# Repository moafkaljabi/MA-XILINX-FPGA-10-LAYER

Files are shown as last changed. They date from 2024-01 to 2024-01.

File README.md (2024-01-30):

# MA-XILINX

                                Front
MA_Inventtronics-FRONT-3D

                                Back
MA_Inventtronics-BACK-3D

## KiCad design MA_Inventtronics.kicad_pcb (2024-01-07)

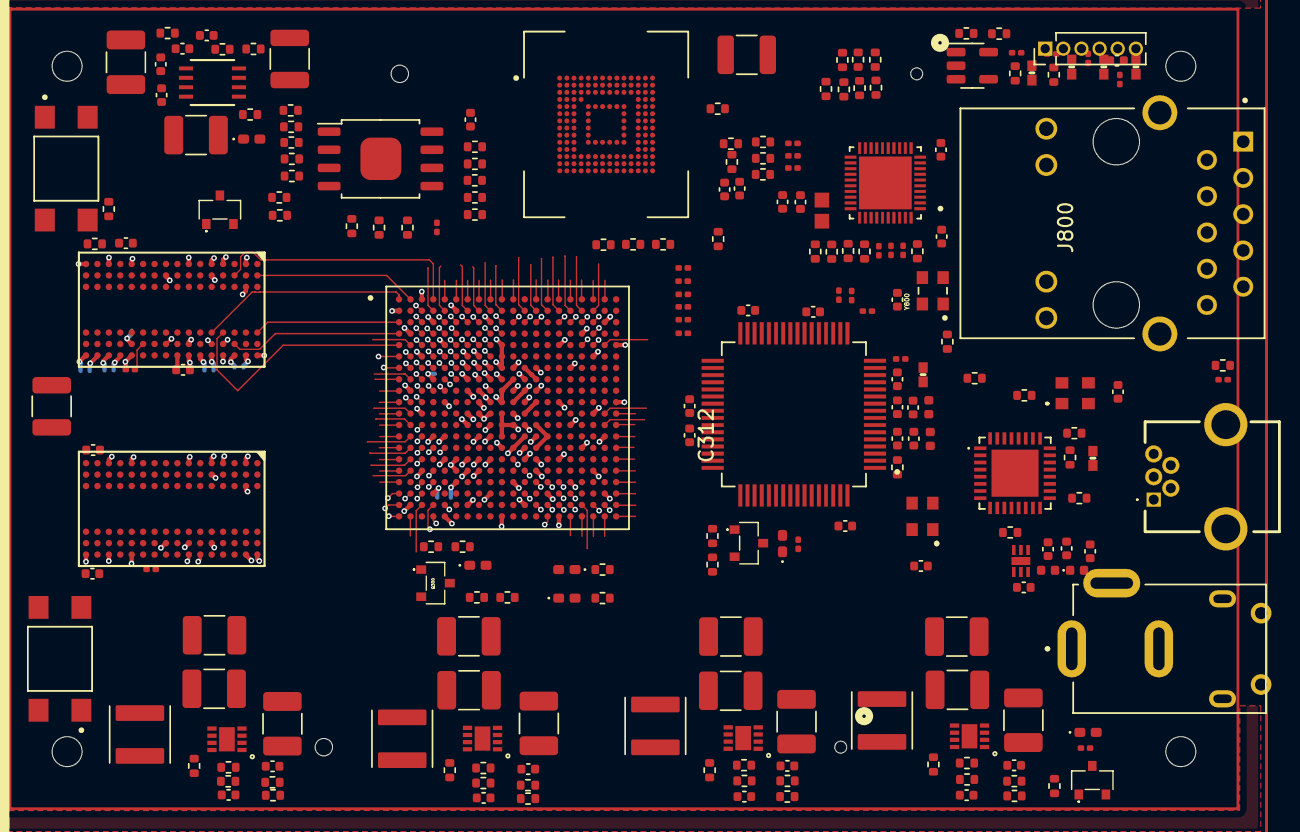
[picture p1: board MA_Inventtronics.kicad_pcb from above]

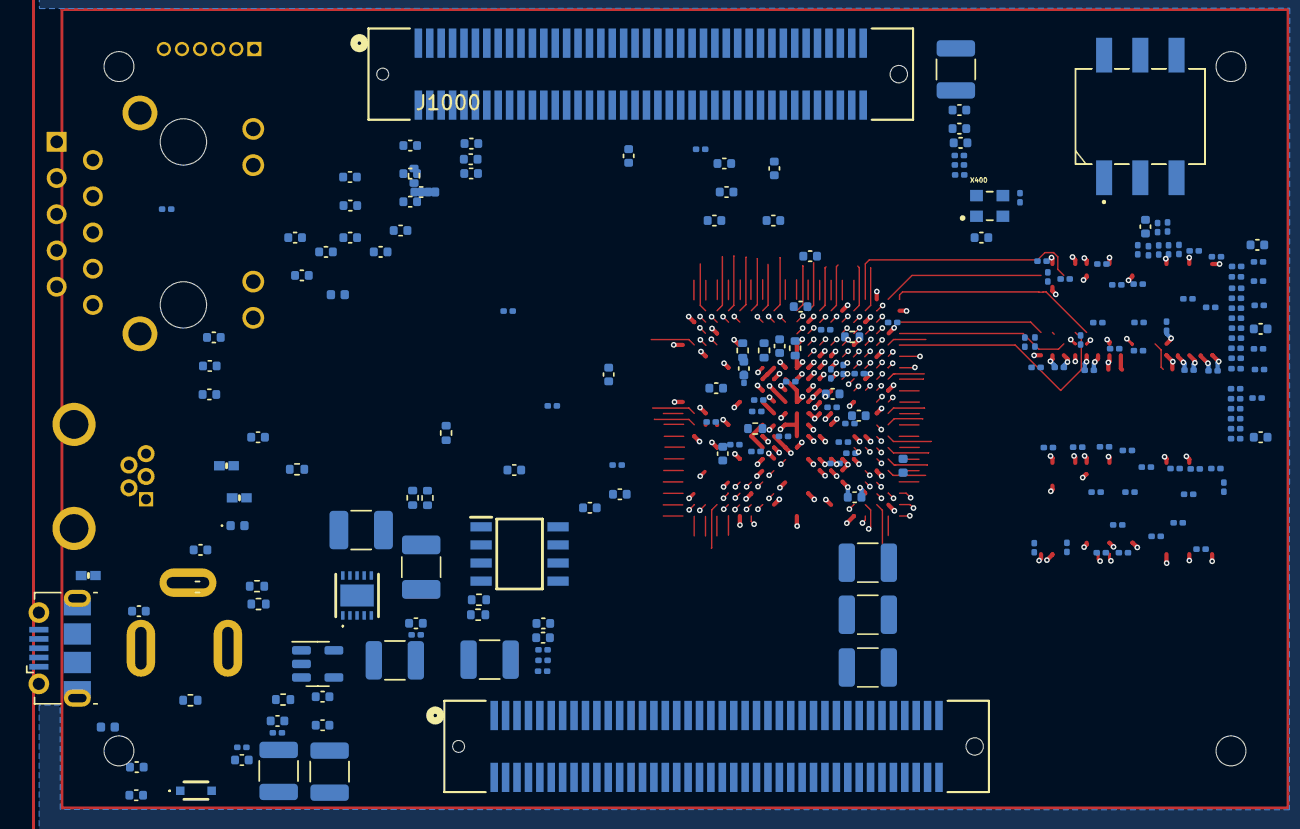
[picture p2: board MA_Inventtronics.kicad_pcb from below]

Board: 10 copper layers, 429 parts (207 on the bottom side), 351 nets.

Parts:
C100, C103, C104, C107, C108, C109, C112, C113, C114, C117, C118, C119, C122, C123, C124, C127: 22u; C_1210_3225Metric_Pad1.33x2.70mm_HandSolder
C101, C102, C105, C110, C115, C120, C300, C304, C306, C307, C308, C309, C310, C311, C312, C313, C314, C316, C318, C400, C401, C402, C403, C404, C405, C406, C407, C409, C412, C801, C802, C803, C804, C805, C806, C807, C808, C810, C811, C813, C815, C817, C818, C900, C901, C902, C903, C904, C905, C906, C908: 100n; C_0402_1005Metric
C106, C111, C116, C121: 22p; C_0402_1005Metric
C125, C126, C128, C129, C201, C205, C210, C213, C216, C220, C223, C229, C232, C237, C239, C244, C246, C301, C302, C303, C305, C315, C408, C410, C411, C413, C608, C609, C610, C611, C702, C712, C724, C734, C800, C809, C812, C814, C816, C819, C907: 4u7; C_0402_1005Metric
C130: 1n; C_0201_0603Metric
C200, C204, C209, C212, C221, C224, C230, C233, C234, C235, C248: 100u; C_1210_3225Metric
C202, C203, C206, C207, C208, C211, C214, C215, C217, C218, C219, C222, C225, C226, C228, C231, C238, C240, C241, C242, C243, C245, C247, C604, C605, C606, C607, C703, C713, C725, C735: 470n; C_0201_0603Metric
C227, C236: 470n; C_0402_1005Metric
C600, C601, C602, C603, C612, C613, C700, C701, C704, C705, C706, C707, C708, C709, C710, C711, C714, C715, C716, C717, C718, C719, C720, C721, C722, C723, C726, C727, C728, C729, C730, C731, C732, C733, C736, C737, C738, C739, C740, C741, C742, C743: 47n; C_0201_0603Metric
D100: PMEG1030EJ; PMEG1030EJ115
D101: LED; LED_0402_1005Metric_Pad0.77x0.64mm_HandSolder
D300, D308, D309: LED_G; LED_0402_1005Metric_Pad0.77x0.64mm_HandSolder
D301, D302, D303, D304, D306, D307, D900, D901, D902: CG0402MLU-3.3G; VARC1005X41N
D305, D903: PMEG1030EJ; D_0402_1005Metric
D400: D400; LED_0402_1005Metric_Pad0.77x0.64mm_HandSolder
D500: GREEN; LED_0402_1005Metric_Pad0.77x0.64mm_HandSolder
FB200, FB300, FB301, FB302, FB800, FB801, FB900: 120R; L_0402_1005Metric
H901, H902, H903, H904: MountingHole; MountingHole_2.1mm
J100: Barrel_Jack_Switch; GRAVITECH_CON-SOCJ-2155
J302: USB_B_Micro; USB_Micro-B_Molex-105017-0001
J304: PinHeader_1x06_P1.27mm_Vertical
J800: HR911130A; HANRUN_HR911130A
J900: GMSB0522132EU
J1000, J1001: 10144518-082802LF; CONN_10144518_AMP
L100, L101, L102, L103: 2u2; L_Abracon_ASPI-4030S
L800: LQM18PN3R3MGHD; INDC1608X100N
Q100, Q300, Q400, Q500: T2N7002AK,LM; TBAT54CLM
R100, R104, R109, R114, R119, R126, R401: 100k; R_0402_1005Metric
R101, R103, R105, R108, R110, R113, R115, R118, R120, R123, R125: 12k; R_0402_1005Metric
R102, R300, R301, R302, R303, R304: 4k7; R_0402_1005Metric
R106, R421, R422, R423, R424, R425: 68K; R_0402_1005Metric
R107, R112, R117, R122, R322, R323, R414, R416, R501: 100K; R_0402_1005Metric
R111: 200K; R_0402_1005Metric
R116: 124K; R_0402_1005Metric
R121: 453K; R_0402_1005Metric
R124, R503, R823: 510R; R_0201_0603Metric
R127, R311, R313, R315, R500, R803, R805, R806, R813, R814: 1K; R_0402_1005Metric
R128: DNP_1M; R_0402_1005Metric
R305, R306, R307, R308, R329, R330, R331, R332, R333, R334, R335, R406, R407, R408, R409, R410, R411, R419, R420, R427, R807, R811, R812, R815, R816, R817: 22R; R_0201_0603Metric
R309, R336, R337, R412, R822: 510R; R_0402_1005Metric
R310, R312, R314, R316, R318, R319, R321, R338, R404, R405: 20K; R_0402_1005Metric
R317, R320, R428: DNP_0R; R_0402_1005Metric
R324, R326, R327, R328, R400, R402, R403, R413, R417, R418, R426, R502, R903: 12K; R_0402_1005Metric
R325, R821: 2K49; R_0402_1005Metric
R600, R626, R627: 100R; R_0201_0603Metric
R601, R602, R603, R604, R605, R606, R607, R608, R609, R610, R611, R612, R613, R614, R615, R616, R617, R618, R619, R620, R621, R622, R623, R624: 49R9; R_0201_0603Metric
R625, R800, R801, R804, R818, R819, R820, R904, R905: 4K7; R_0402_1005Metric
R700, R701: 240R; R_0201_0603Metric
R802: DNP_4K7; R_0402_1005Metric
R808, R809, R810, R901: 22R; R_0402_1005Metric
R900: 1k; R_0402_1005Metric
R902: 8K06; R_0402_1005Metric
SW300, SW400: TL3305BF160QG; SW_TL3305BF160QG
SW301: 219-3LPST; 2193LPST
U100: LS1205EVD33
U101, U102, U103, U104: SY8003ADFC; SON50P200X200X65-9N
U105: BD3539FVM-TR; MSOP8_ROM
U200: XC7Z007S-1CLG400C; BGA400C80P20X20_1700X1700X160N
U300: FT2232HL-REEL; QFP50P1200X1200X160-64N
U301: 93LC56B-I_SN; SOIC127P600X175-8N
U400, U401: SN74LVC1G14DBV; SOT-23-5
U403: S40FC004C1B1I00000; BGA153N50P14X14_1150X1300X80
U404: W25Q128JVEIQ; SOIC-8_5.23x5.23mm_P1.27mm
U700, U701: MT41K256M16TW-107_P; TFBGA-96
U800: RTL8211F-CG; QFN40P500X500X90-41N
U900: USB3320C-EZK-TR; QFN50P500X500X100-33N330X330
U901: MIC2099-1YMT-TR; TMLF-6_MT_MCH
X300: ECS-2520MV-120-BN-TR; ECS2520MV120BNTR
X400: ECS-2520MV-333.3-BN-TR; OSC_ECS-2520S25-250-FN-TR
Y800: ECS-2520MV-250-BN-TR; OSC_ECS-2520S25-250-FN-TR
Y900: ECS-2520MV-130-BN-TR; ECS2520MV130BNTR

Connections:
+5V: C104.1, C109.1, C114.1, C119.1, R103.1, R105.1, R108.1, R113.1, R118.1, U101.3 (IN), U102.3 (IN), U103.3 (IN), U104.3 (IN)
/1. Power/DDR_VTT_EN: C125.1, R125.2, R126.1, R127.2, U105.2 (EN), U105.5 (VDDQ)
/1. Power/EN_1V0: R105.2, R110.2, R115.2, R120.2, U101.7 (EN), U102.7 (EN), U103.7 (EN), U104.7 (EN)
/1. Power/FB 1V0: C106.2, C111.2, C116.2, C121.2, R106.2, R107.1, R111.2, R112.1, R116.2, R117.1, R121.2, R122.1, U101.1 (FB), U102.1 (FB), U103.1 (FB), U104.1 (FB)
/1. Power/LED_PWR_A: D101.2 (A), R124.2
/1. Power/LED_PWR_C: D101.1 (K), Q100.2 (S)
/1. Power/PG_1V0: C105.1, C110.1, C115.1, C120.1, R103.2, R104.1, R108.2, R109.1, R113.2, R114.1, R118.2, R119.1, R123.2, U101.2 (PG), U102.2 (PG), U103.2 (PG), U104.2 (PG)
/1. Power/PWR_EN: C101.1, R100.2, U100.7 (EN)
/1. Power/SW_1V0: L100.1, L101.1, L102.1, L103.1, U101.6 (LX), U102.6 (LX), U103.6 (LX), U104.6 (LX)
/1. Power/eFuse_ILIM: R102.1, U100.5 (ILIM)
/1. Power/eFuse_SS: C102.1, U100.6 (SS)
/1. Power/eFuse_VCP: R101.1, U100.4 (VCP)
/3. Zynq Config, JTAG, Debug/CLK 12 MHZ: R338.1, X300.3 (OUT)
/3. Zynq Config, JTAG, Debug/DONE: Q300.1 (G), R302.2, U200.R11 (DONE_0)
/3. Zynq Config, JTAG, Debug/FTDI EECLK: R326.1, U300.62 (EECLK), U301.2 (CLK)
/3. Zynq Config, JTAG, Debug/FTDI EECS: R327.1, U300.63 (EECS), U301.1 (CS)
/3. Zynq Config, JTAG, Debug/FTDI EEDAT: R325.2, U300.61 (EEDATA), U301.3 (DI)
/3. Zynq Config, JTAG, Debug/FTDI NRST: R322.1, R323.2, U300.14 (~RESET)
/3. Zynq Config, JTAG, Debug/FTDI OSCI: R338.2, U300.2 (OSCI)
/3. Zynq Config, JTAG, Debug/FTDI REF: R328.2, U300.6 (REF)
/3. Zynq Config, JTAG, Debug/FTDI RX: R335.2, U300.39 (BDBUS1)
/3. Zynq Config, JTAG, Debug/FTDI TCK: R329.1, U300.16 (ADBUS0)
/3. Zynq Config, JTAG, Debug/FTDI TDI: R330.1, U300.17 (ADBUS1)
/3. Zynq Config, JTAG, Debug/FTDI TDO: R331.1, U300.18 (ADBUS2)
/3. Zynq Config, JTAG, Debug/FTDI TMS: R332.1, U300.19 (ADBUS3)
/3. Zynq Config, JTAG, Debug/FTDI TX: R334.2, U300.38 (BDBUS0)
/3. Zynq Config, JTAG, Debug/FTDI VPHY: C305.1, C306.1, FB302.2, U300.4 (VPHY)
/3. Zynq Config, JTAG, Debug/FTDI VPLL: C303.1, C304.1, FB301.2, U300.9 (VPLL)
/3. Zynq Config, JTAG, Debug/FTDI_RX_LED_A: D308.2 (A), R336.2
/3. Zynq Config, JTAG, Debug/FTDI_RX_LED_K: D308.1 (K), U300.54 (BCBUS3)
/3. Zynq Config, JTAG, Debug/FTDI_TX_LED_A: D309.2 (A), R337.2
/3. Zynq Config, JTAG, Debug/FTDI_TX_LED_K: D309.1 (K), U300.55 (BCBUS4)
/3. Zynq Config, JTAG, Debug/LED_DONE_A: D300.2 (A), R309.2
/3. Zynq Config, JTAG, Debug/LED_DONE_C: D300.1 (K), Q300.3 (D)
/3. Zynq Config, JTAG, Debug/M0: R310.1, R315.1, SW301.1
/3. Zynq Config, JTAG, Debug/M1: R312.1, R313.1, SW301.2
/3. Zynq Config, JTAG, Debug/M2: R311.1, R314.2, SW301.3
/3. Zynq Config, JTAG, Debug/M3: R316.2, R317.2, R318.1
/3. Zynq Config, JTAG, Debug/M4: R319.2, R320.2, R321.1
/3. Zynq Config, JTAG, Debug/NINIT: R303.2, U200.R10 (INIT_B_0)
/3. Zynq Config, JTAG, Debug/NPROGARAM: R304.2, SW300.3, SW300.4, U200.L6 (PROGRAM_B_0)
/3. Zynq Config, JTAG, Debug/USB FTDI D N: D306.2, D307.2, J302.2 (D-), U300.7 (DM)
/3. Zynq Config, JTAG, Debug/USB FTDI D P: J302.3 (D+), U300.8 (DP)
/3. Zynq Config, JTAG, Debug/VUSB FILTER: C302.1, D305.2 (A), FB300.2, R322.2
/4. Zynq Processing System (PS)/CLK 33M33: R420.1, X400.3 (OUT)
/4. Zynq Processing System (PS)/FLASH CLK M4: R419.2, U404.6 (CLK)
/5. Zynq Programmable Logic (PL)/LED PL: R501.1, R502.1, U200.T12 (IO_L2P_T0_34)
/5. Zynq Programmable Logic (PL)/NPUDC: R500.2, U200.U13 (IO_L3P_T0_DQS_PUDC_B_34)
/6. Zynq DDR Interface & Termination/DDR NRST: R625.2, U200.B4 (PS_DDR_DRST_B_502)
/7. 1GB DDR3L Modules/DDR ZQ1: R700.1, U700.L8 (ZQ)
/7. 1GB DDR3L Modules/DDR ZQ2: R701.1, U701.L8 (ZQ)
/8. Gigabit Ethernet/CLK 25MHZ: R815.1, Y800.3 (OUT)
/8. Gigabit Ethernet/ETH CLK 25MHZ: R815.2, U800.37 (XTAL_OUT/EXT_CLK)
/8. Gigabit Ethernet/ETH PHY RXCLK: R812.2, U800.27 (RXC/PHYAD1)
/8. Gigabit Ethernet/ETH PHY RXCTL: R811.2, U800.26 (RXCTL/PHYAD2)
/8. Gigabit Ethernet/ETH PHY RXD0: J800.2, J800.4, J800.5, J800.8, R807.2, U800.1 (MDIP0), U800.4 (MDIP1), U800.6 (MDIP2), U800.9 (MDIP3), U800.25 (RXD0/RXDLY)
/8. Gigabit Ethernet/ETH PHY RXD1: J800.3, J800.6, J800.7, J800.9, R808.2, U800.2 (MDIN0), U800.5 (MDIN1), U800.7 (MDIN2), U800.10 (MDIN3), U800.24 (RXD1/TXDLY)
/8. Gigabit Ethernet/ETH PHY RXD2: R809.2, U800.23 (RXD2/PLLOFF)
/8. Gigabit Ethernet/ETH PHY RXD3: R810.2, U800.22 (RXD3/PHYAD0)
/8. Gigabit Ethernet/ETH REG OUT: L800.1, U800.30 (REG_OUT)
/8. Gigabit Ethernet/ETH RSET: R821.2, U800.39 (RSET)
/8. Gigabit Ethernet/ETH XTAL IN: R816.1, U800.36 (XTAL_IN)
/8. Gigabit Ethernet/ETH XTALOUT: R817.1, U800.35 (CLKOUT)
/9. USB 2.0 High-Speed (OTG)/CLK 13MHZ: R901.1, Y900.3 (OUT)
/9. USB 2.0 High-Speed (OTG)/USB HS D N: D900.2, J900.2 (D-), U900.19 (DM)
/9. USB 2.0 High-Speed (OTG)/USB HS D P: D901.2, J900.3 (D+), U900.18 (DP)
/9. USB 2.0 High-Speed (OTG)/USB HS ID: D902.2, J900.4 (ID), U900.23 (ID)
/9. USB 2.0 High-Speed (OTG)/USB HS VBUS FILT: C905.1, D903.1 (K), FB900.1, R903.2
/9. USB 2.0 High-Speed (OTG)/USB ILM: R905.1, U901.2 (ILIMIT)
/9. USB 2.0 High-Speed (OTG)/USB PHY RBIAS: R902.1, U900.24 (RBIAS)
/9. USB 2.0 High-Speed (OTG)/USB PHY VBUS: R903.1, U900.22 (VBUS)
/9. USB 2.0 High-Speed (OTG)/USB REFCLK 13MHZ: R901.2, U900.26 (REFCLK)
DDR A0: R609.1, U200.N2 (PS_DDR_A0_502), U700.N3 (A0), U701.N3 (A0)
DDR A1: R610.1, U200.K2 (PS_DDR_A1_502), U700.P7 (A1), U701.P7 (A1)
DDR A2: R611.1, U200.M3 (PS_DDR_A2_502), U700.P3 (A2), U701.P3 (A2)
DDR A3: R612.1, U200.K3 (PS_DDR_A3_502), U700.N2 (A3), U701.N2 (A3)
DDR A4: R613.1, U200.M4 (PS_DDR_A4_502), U700.P8 (A4), U701.P8 (A4)
DDR A5: R614.1, U200.L1 (PS_DDR_A5_502), U700.P2 (A5), U701.P2 (A5)
DDR A6: R615.1, U200.L4 (PS_DDR_A6_502), U700.R8 (A6), U701.R8 (A6)
DDR A7: R616.1, U200.K4 (PS_DDR_A7_502), U700.R2 (A7), U701.R2 (A7)
DDR A8: R617.1, U200.K1 (PS_DDR_A8_502), U700.T8 (A8), U701.T8 (A8)
DDR A9: R618.1, U200.J4 (PS_DDR_A9_502), U700.R3 (A9), U701.R3 (A9)
DDR A10: R619.1, U200.F5 (PS_DDR_A10_502), U700.L7 (A10/AP), U701.L7 (A10/AP)
DDR A11: R620.1, U200.G4 (PS_DDR_A11_502), U700.R7 (A11), U701.R7 (A11)
DDR A12: R621.1, U200.E4 (PS_DDR_A12_502), U700.N7 (A12/BC#), U701.N7 (A12/BC#)
DDR A13: R622.1, U200.D4 (PS_DDR_A13_502), U700.T3 (A13), U701.T3 (A13)
DDR A14: R623.1, U200.F4 (PS_DDR_A14_502), U700.T7 (A14), U701.T7 (A14)
DDR BA0: R606.1, U200.L5 (PS_DDR_BA0_502), U700.M2 (BA0), U701.M2 (BA0)
DDR BA1: R607.1, U200.R4 (PS_DDR_BA1_502), U700.N8 (BA1), U701.N8 (BA1)
DDR BA2: R608.1, U200.J5 (PS_DDR_BA2_502), U700.M3 (BA2), U701.M3 (BA2)
DDR CK N: R600.1, U200.M2 (PS_DDR_CKN_502), U700.K7 (CLKN), U701.K7 (CLKN)
DDR CK P: R600.2, U200.L2 (PS_DDR_CKP_502), U700.J7 (CLKP), U701.J7 (CLKP)
DDR CKE: R601.1, U200.N3 (PS_DDR_CKE_502), U700.K9 (CKE), U701.K9 (CKE)
DDR DM0: U200.A1 (PS_DDR_DM0_502), U700.E7 (DML)
DDR DM1: U200.F1 (PS_DDR_DM1_502), U700.D3 (DMU)
DDR DM2: U200.T1 (PS_DDR_DM2_502), U701.E7 (DML)
DDR DM3: U200.Y1 (PS_DDR_DM3_502), U701.D3 (DMU)
DDR DQ0: U200.C3 (PS_DDR_DQ0_502), U700.A3 (DQU7)
DDR DQ1: U200.B3 (PS_DDR_DQ1_502), U700.C3 (DQU1)
DDR DQ2: U200.A4 (PS_DDR_DQ3_502), U700.C2 (DQU3)
DDR DQ3: U200.A2 (PS_DDR_DQ2_502), U700.A2 (DQU5)
DDR DQ4: U200.D3 (PS_DDR_DQ4_502), U700.B8 (DQU6)
DDR DQ5: U200.E1 (PS_DDR_DQ7_502), U700.D7 (DQU0)
DDR DQ6: U200.C1 (PS_DDR_DQ6_502), U700.A7 (DQU4)
DDR DQ7: U200.D1 (PS_DDR_DQ5_502), U700.C8 (DQU2)
DDR DQ8: U200.E2 (PS_DDR_DQ8_502), U700.H3 (DQL4)
DDR DQ9: U200.E3 (PS_DDR_DQ9_502), U700.E3 (DQL0)
DDR DQ10: U200.G3 (PS_DDR_DQ10_502), U700.G2 (DQL6)
DDR DQ11: U200.H3 (PS_DDR_DQ11_502), U700.H7 (DQL7)
DDR DQ12: U200.J3 (PS_DDR_DQ12_502), U700.F7 (DQL1)
DDR DQ13: U200.H2 (PS_DDR_DQ13_502), U700.H8 (DQL5)
DDR DQ14: U200.H1 (PS_DDR_DQ14_502), U700.F2 (DQL2)
DDR DQ15: U200.J1 (PS_DDR_DQ15_502), U700.F8 (DQL3)
DDR DQ16: U200.P1 (PS_DDR_DQ16_502), U701.E3 (DQL0)
DDR DQ17: U200.P3 (PS_DDR_DQ17_502), U701.H3 (DQL4)
DDR DQ18: U200.R3 (PS_DDR_DQ18_502), U701.G2 (DQL6)
DDR DQ19: U200.R1 (PS_DDR_DQ19_502), U701.F2 (DQL2)
DDR DQ20: U200.T4 (PS_DDR_DQ20_502), U701.F7 (DQL1)
DDR DQ21: U200.U4 (PS_DDR_DQ21_502), U701.F8 (DQL3)
DDR DQ22: U200.U2 (PS_DDR_DQ22_502), U701.H8 (DQL5)
DDR DQ23: U200.U3 (PS_DDR_DQ23_502), U701.H7 (DQL7)
DDR DQ24: U200.V1 (PS_DDR_DQ24_502), U701.A2 (DQU5)
DDR DQ25: U200.Y3 (PS_DDR_DQ25_502), U701.C8 (DQU2)
DDR DQ26: U200.W1 (PS_DDR_DQ26_502), U701.A3 (DQU7)
DDR DQ27: U200.Y4 (PS_DDR_DQ27_502), U701.B8 (DQU6)
DDR DQ28: U200.Y2 (PS_DDR_DQ28_502), U701.C3 (DQU1)
DDR DQ29: U200.W3 (PS_DDR_DQ29_502), U701.D7 (DQU0)
DDR DQ30: U200.V2 (PS_DDR_DQ30_502), U701.C2 (DQU3)
DDR DQ31: U200.V3 (PS_DDR_DQ31_502), U701.A7 (DQU4)
DDR DQS0 N: U200.B2 (PS_DDR_DQS_N0_502), U700.B7 (DQSUN)
DDR DQS0 P: U200.C2 (PS_DDR_DQS_P0_502), U700.C7 (DQSUP)
DDR DQS1 N: U200.F2 (PS_DDR_DQS_N1_502), U700.G3 (DQSLN)
DDR DQS1 P: U200.G2 (PS_DDR_DQS_P1_502), U700.F3 (DQSLP)
DDR DQS2 N: U200.T2 (PS_DDR_DQS_N2_502), U701.G3 (DQSLN)
DDR DQS2 P: U200.R2 (PS_DDR_DQS_P2_502), U701.F3 (DQSLP)
DDR DQS3 N: U200.W4 (PS_DDR_DQS_N3_502), U701.B7 (DQSUN)
DDR DQS3 P: U200.W5 (PS_DDR_DQS_P3_502), U701.C7 (DQSUP)
DDR NCAS: R604.1, U200.P5 (PS_DDR_CAS_B_502), U700.K3 (CAS#), U701.K3 (CAS#)
DDR NCS: R602.1, U200.N1 (PS_DDR_CS_B_502), U700.L2 (CS#), U701.L2 (CS#)
DDR NRAS: R603.1, R605.1, U200.M5 (PS_DDR_WE_B_502), U200.P4 (PS_DDR_RAS_B_502), U700.J3 (RAS#), U700.L3 (WE#), U701.J3 (RAS#), U701.L3 (WE#)
DDR NRST: U700.T2 (RESET#), U701.T2 (RESET#)
DDR ODT: R624.1, U200.N5 (PS_DDR_ODT_502), U700.K1 (ODT), U701.K1 (ODT)
ETH MDC: U200.C10 (PS_MIO17_501), U800.13 (MDC)
ETH MDIO: R814.1, U200.C11 (PS_MIO15_500), U800.14 (MDIO)
ETH NINT: R813.1, U200.E12 (PS_MIO38_501), U800.31 (INTB/PMEB)
ETH NRST: R416.1, U200.C17 (PS_MIO40_501), U401.2, U800.12 (PHYRSTB)
ETH NRST +3V3: R417.2, U401.4
ETH PHY TXCLK: R406.2, U800.20 (TXC)
ETH PHY TXCTL: R411.2, U800.19 (TXCTL)
ETH PHY TXD0: R407.2, U800.18 (TXD0)
ETH PHY TXD1: R408.2, U800.17 (TXD1)
ETH PHY TXD2: R409.2, U800.16 (TXD2)
ETH PHY TXD3: R410.2, U800.15 (TXD3)
ETH RXCLK: R806.2, R812.1, U200.B17 (PS_MIO37_501)
ETH RXCTL: R805.2, R811.1, U200.D13 (PS_MIO28_501)
ETH RXD0: R800.1, R807.1, U200.D11 (PS_MIO36_501)
ETH RXD1: R801.1, R808.1, U200.A16 (PS_MIO34_501)
ETH RXD2: R802.1, R803.2, R809.1, U200.F15 (PS_MIO32_501)
ETH RXD3: R804.1, R810.1, U200.A15 (PS_MIO30_501)
Earth: C100.2, C101.2, C102.2, C103.2, C104.2, C105.2, C107.2, C108.2, C109.2, C110.2, C112.2, C113.2, C114.2, C115.2, C117.2, C118.2, C119.2, C120.2, C122.2, C123.2, C124.2, C125.2, C126.2, C127.2, C128.2, C129.2, C130.2, J100.2, J100.3, Q100.3 (D), R102.2, R104.2, R107.2, R109.2, R110.1, R112.2, R114.2, R115.1, R117.2, R119.2, R120.1, R122.2, R126.2, R128.2, U100.11 (GND), U101.8 (SGND), U102.8 (SGND), U103.8 (SGND), U104.8 (SGND), U105.1 (GND)
GNDPWR: C130.1, J302.6 (Shield), J800.S1 (SHIELD), J800.S2 (SHIELD), J900.SH, R128.1
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
